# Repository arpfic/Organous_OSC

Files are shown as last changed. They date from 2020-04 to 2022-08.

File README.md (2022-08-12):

# Organous_OSC

This folder contains hardware designs and software for the Orguanous, a prototype pipe organ.

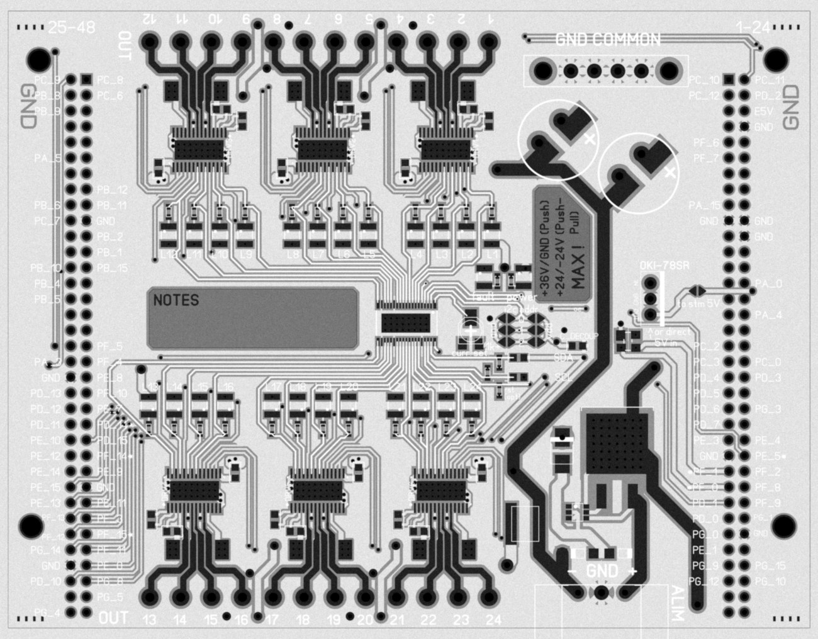
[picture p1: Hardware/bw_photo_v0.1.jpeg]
Organous OSC v0.1


Principal code maintainer : Damien Leblois <damienleb@protonmail.com>

https://arpfic.notion.site/Electronique-pour-orgue-326637f6daa6430288f5e7deb4299960
https://www.violonaroue.fr/Orguanous

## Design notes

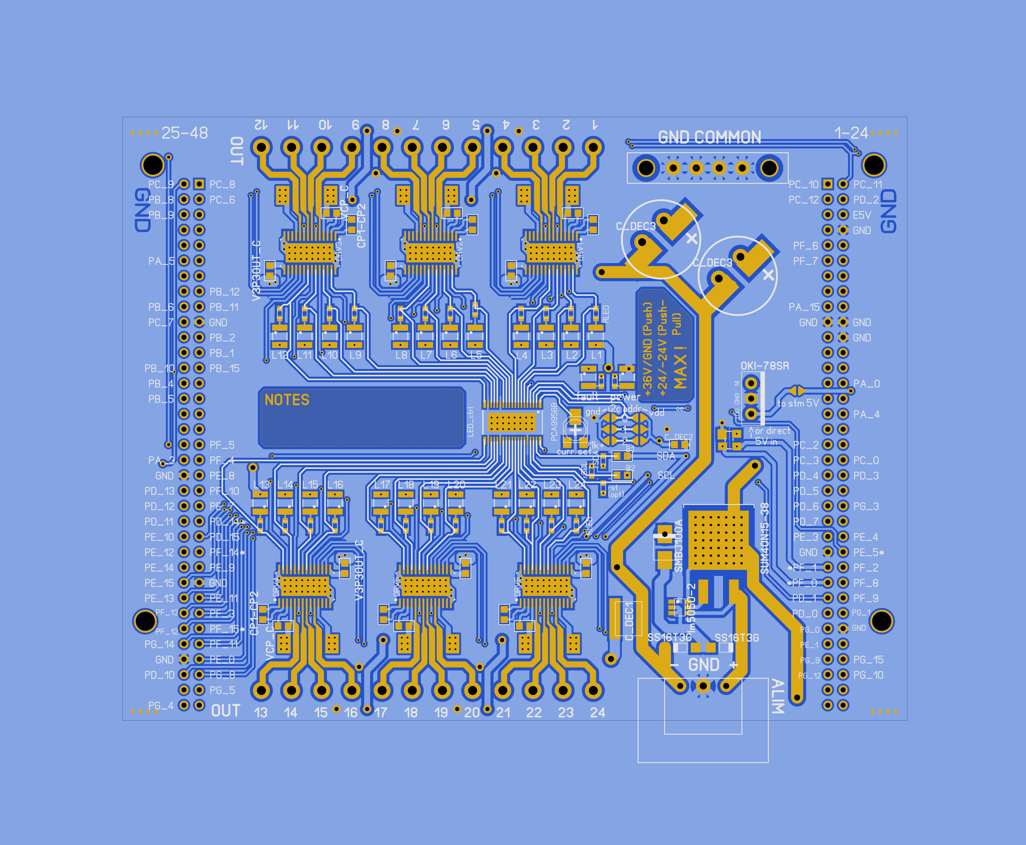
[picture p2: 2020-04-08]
Hardware/Organous_OSC_v0.2_top.png

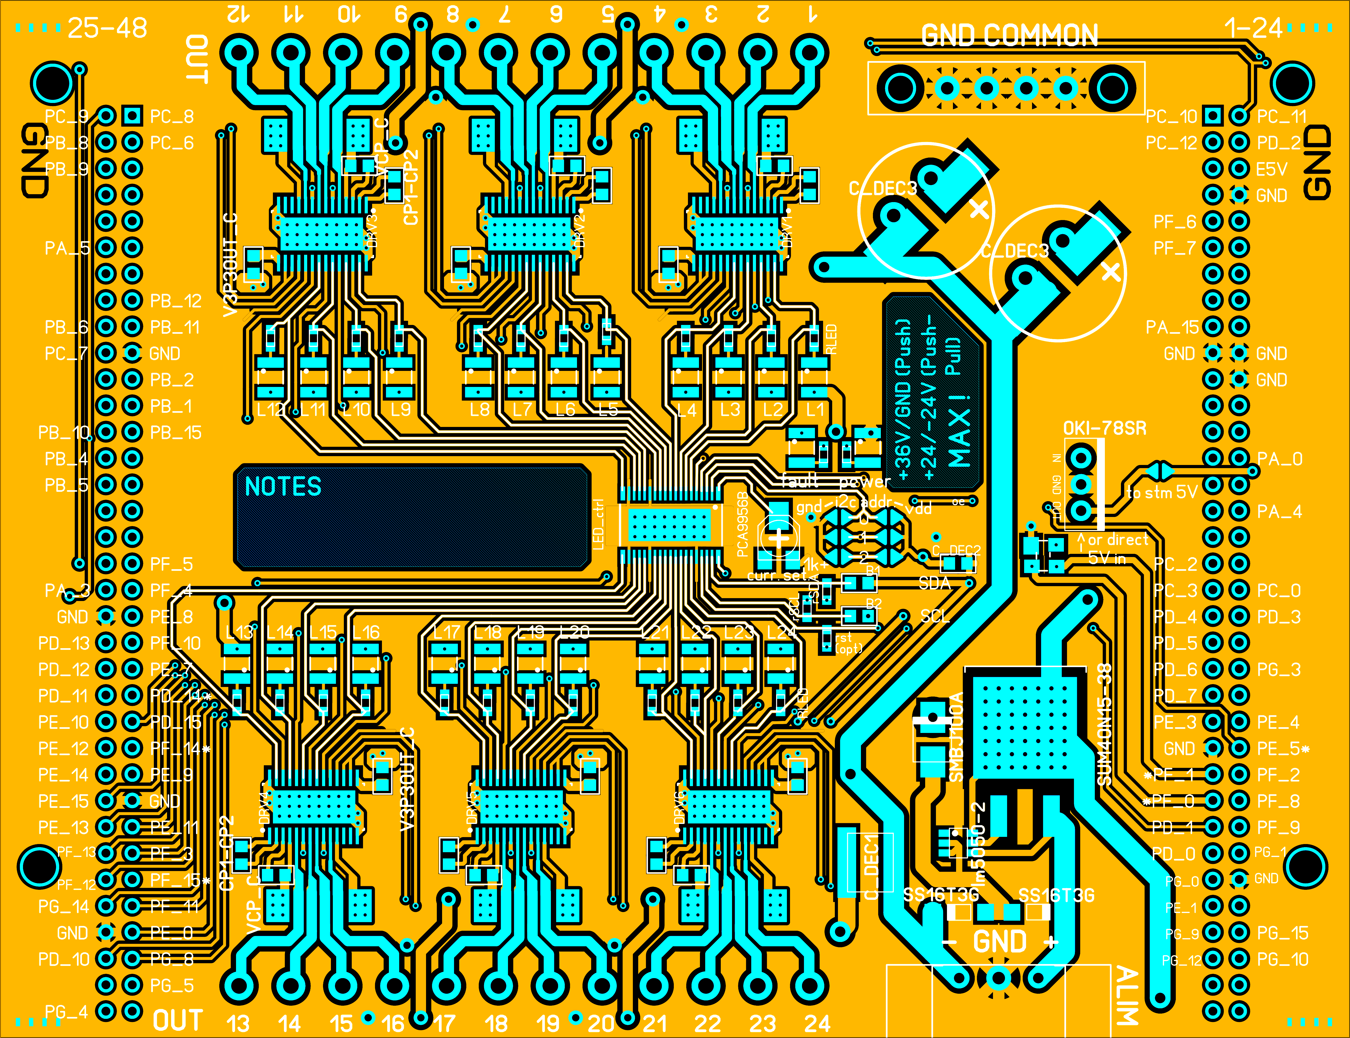
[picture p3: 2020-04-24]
Hardware/carte_osc_fonctions_v0.2_top.png

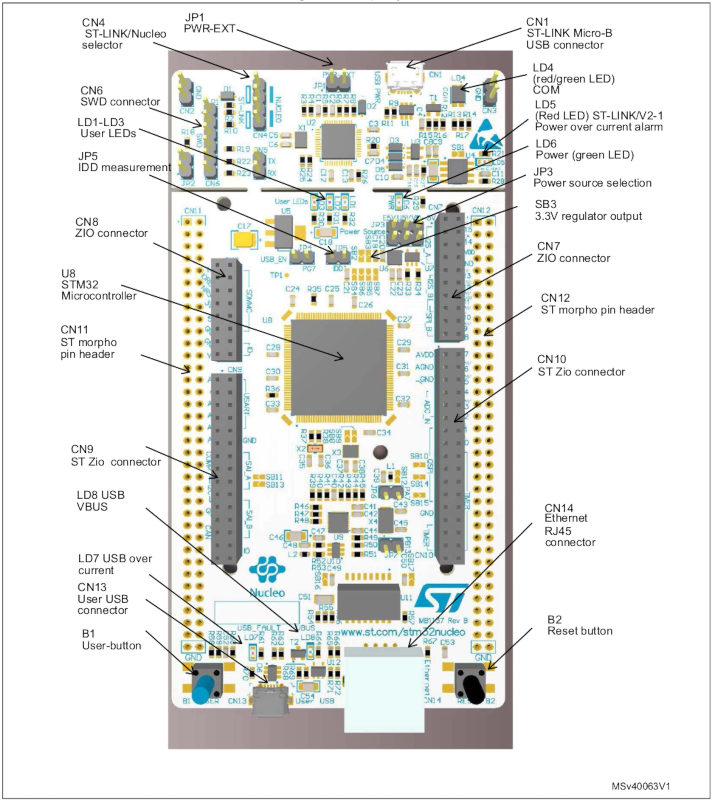
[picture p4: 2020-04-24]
Hardware/Nucleo_144.jpg

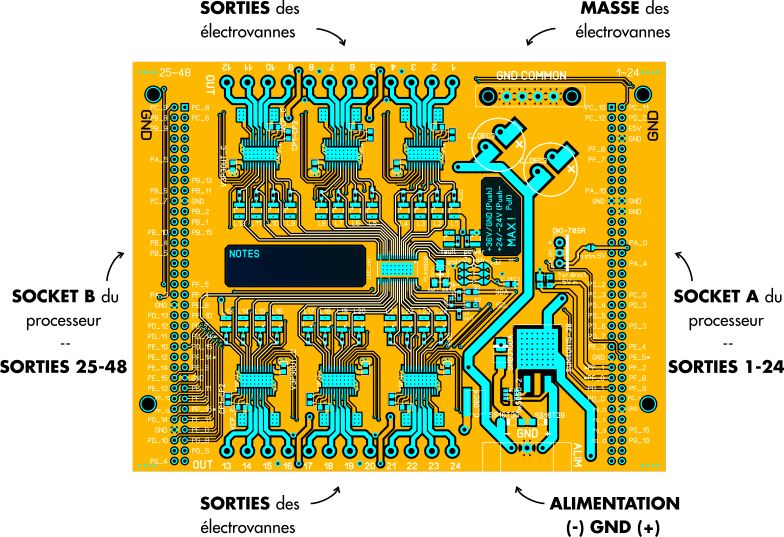
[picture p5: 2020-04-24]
Hardware/carte_osc_fonctions.png

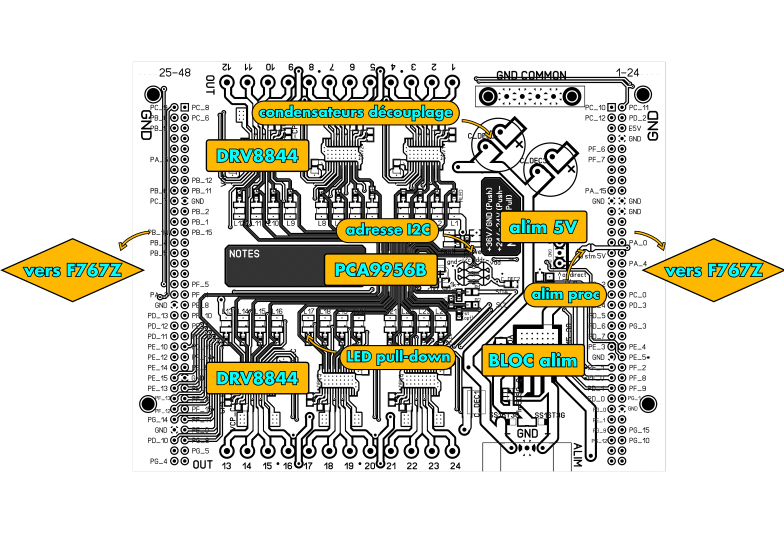
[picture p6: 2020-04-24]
Hardware/carte_osc_fonctions_avancees.png

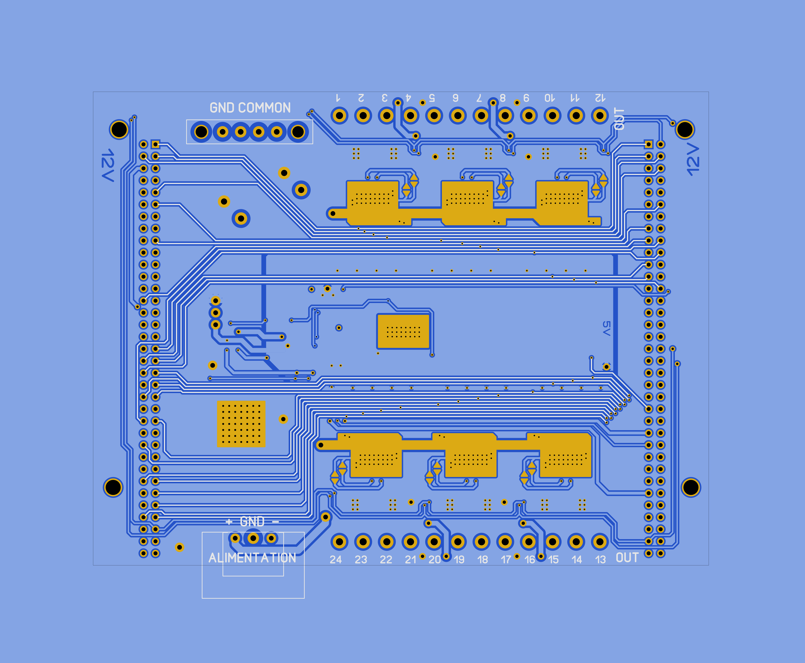
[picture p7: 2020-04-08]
Hardware/Organous_OSC_v0.2_bottom.png

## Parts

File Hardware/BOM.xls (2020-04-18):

ORGANOUS_TOT_10_03_2020
N° Mouser | N° de fab. | Fabricant | N° client | Description | RoHS | Cycle de vie | Qté. | Prix (EUR) | Ext. : (EUR)
855-M20-7832046 | M20-7832046 | Harwin |  | Embases et logements de câbles 20+20 DIL VERTICAL SOCKET TIN | RoHS : conforme |  | 2 | 2,76 € | 5,52 €
595-DRV8844PWPR | DRV8844PWPR | Texas Instruments |  | Contrôleurs et pilotes de moteur / de mouvement / d'allumage Brushed DC motor Solenoid/Relay Drvr | RoHS : conforme |  | 6 | 2,97 € | 17,82 €
580-OKI78SR51.5W36HC | OKI-78SR-5/1.5-W36H-C | Murata |  | Convertisseurs CC-CC non isolés 7.5W 24V 5Vout 1.5A Horizontal Mount | RoHS : conforme |  | 1 | 3,87 € | 3,87 €
771-PCA9956BTWY | PCA9956BTWY | NXP |  | Étage pilote pour LED I2C LED Display Control | RoHS : conforme |  | 1 | 1,41 € | 1,41 €
651-1830619 | 1830619 | Phoenix Contact |  | Borniers enfichable 4 Pos 3.81mm pitch Through Hole Header | RoHS : conforme |  | 1 | 3,27 € | 3,27 €
651-1828362 | 1828362 | Phoenix Contact |  | Borniers enfichable 4 Pos 3.81mm pitch Plug 28-16 AWG Screw | RoHS : conforme |  | 1 | 4,34 € | 4,34 €
490-TBP02R1W-38103BE | TBP02R1W-381-03BE | CUI Devices |  | Borniers enfichable Terminal block, pluggable, w screw lock, 3.81, receptical, 3 pole, blue |  | Nouveau produit | 1 | 0,603 € | 0,60 €
490-TBP02P1W-38103BE | TBP02P1W-381-03BE | CUI Devices |  | Borniers enfichable Terminal block, pluggable, 3.81, plug, 3 pole, slotted screw, blue |  | Nouveau produit | 1 | 0,909 € | 0,91 €
651-1988943 | 1988943 | Phoenix Contact |  | Borniers fixes PTA 1.5/16-5.0 | RoHS : conforme |  | 2 | 2,76 € | 5,52 €
81-BLM18BD471SN1D | BLM18BD471SN1D | Murata |  | Perles de ferrite 0603 470 OHM | RoHS : conforme |  | 2 | 0,09 € | 0,18 €
603-CC603KRX7R9BB103 | CC0603KRX7R9BB103 | Yageo |  | Condensateurs céramique multicouches MLCC - CMS 10nF 50V X7R 10% | RoHS : conforme |  | 6 | 0,09 € | 0,54 €
603-CC603KRX7R9BB104 | CC0603KRX7R9BB104 | Yageo |  | Condensateurs céramique multicouches MLCC - CMS 100nF 50V X7R 10% | RoHS : conforme |  | 7 | 0,09 € | 0,63 €
603-CC0603KR9BB474 | CC0603KRX5R9BB474 | Yageo |  | Condensateurs céramique multicouches MLCC - CMS .47uF 50V 10% 0603 Case Size | RoHS : conforme |  | 6 | 0,531 € | 3,19 €
77-VJ1825Y105MXBAT | VJ1825Y105MXBAT | Vishay |  | Condensateurs céramique multicouches MLCC - CMS 1.0uF 100volts 20% | RoHS : conforme |  | 1 | 1,77 € | 1,77 €
667-EEE-FK2A470AV | EEE-FK2A470AV | Panasonic |  | Condensateurs électrolytiques en aluminium - CMS 100VDC 47uF 20% Anti-Vibe AEC-Q200 | RoHS : conforme | Nouveau produit | 2 | 1,71 € | 3,42 €
863-SS16T3G | SS16T3G | ON Semiconductor |  | Diodes et redresseurs Schottky 1A 60V | RoHS : conforme |  | 2 | 0,144 € | 0,29 €
652-SMBJ100A | SMBJ100A | Bourns |  | Suppresseurs ESD / diodes TVS 100volts 5uA 3.7 Amps Uni-Dir | Conforme à RoHS par dispense |  | 1 | 0,414 € | 0,41 €
926-LM5050MK-2/NOPB | LM5050MK-2/NOPB | Texas Instruments |  | Contrôleurs de tension à remplacement à chaud Hi Side OR-ing FET Cntlr | RoHS : conforme |  | 1 | 1,98 € | 1,98 €
859-LTST-C930KFKT | LTST-C930KFKT | Lite-On |  | DEL standard - CMS Orange Clear 605nm | RoHS : conforme |  | 25 | 0,18 € | 4,50 €
859-LTST-C930GKT | LTST-C930GKT | Lite-On |  | DEL standard - CMS Green Clear 569nm | RoHS : conforme |  | 1 | 0,342 € | 0,34 €
78-SUM80090E-GE3 | SUM80090E-GE3 | Vishay |  | MOSFET 150V Vds 20V Vgs D2PAK (TO-263) | RoHS : conforme |  | 1 | 2,70 € | 2,70 €
771-PRTR5V0U2AX,235 | PRTR5V0U2AX,235 | Nexperia |  | Suppresseurs ESD / diodes TVS Diode TVS Single Uni-Dir 5.5V 4-Pin | RoHS : conforme |  | 1 | 0,468 € | 0,47 €
603-RC0603FR-07270RL | RC0603FR-07270RL | Yageo |  | Résistances à couches épaisses - CMS 270 OHM 1% | Conforme à RoHS par dispense |  | 2 | 0,09 € | 0,18 €
603-RC0603FR-071KL | RC0603FR-071KL | Yageo |  | Résistances à couches épaisses - CMS 1K OHM 1% | Conforme à RoHS par dispense |  | 24 | 0,016 € | 0,38 €
72-TS53YJ-10K | TS53YJ103MR10 | Vishay |  | Résistances ajustables - SMD 5MM SQ SMD 103 | Conforme à RoHS par dispense |  | 1 | 1,13 € | 1,13 €
603-RC0603FR-071K6L | RC0603FR-071K6L | Yageo |  | Résistances à couches épaisses - CMS 1.6K OHM 1% | Conforme à RoHS par dispense |  | 2 | 0,09 € | 0,18 €
859-LTST-C930EKT | LTST-C930EKT | Lite-On |  | DEL standard - CMS Red Clear 621nm | RoHS : conforme |  | 1 | 0,351 € | 0,35 €
144-MTS-11 | MTS-11 | Essentra |  | Écarteurs et entretoises Stndff,Thrd,Hex,Natural,11MM Spc | RoHS : conforme | Nouveau chez Mouser | 2 | 0,72 € | 1,44 €
534-29341 | 29341 | Keystone Electronics |  | Vis et attaches M3 6.0mm NYL SCRW | RoHS : conforme |  | 4 | 0,20 € | 0,40 €
568-NE8FDV-TOP | NE8FDV-TOP | Neutrik |  | Connecteurs modulaires / Connecteurs Ethernet CAT5 D PCB Panel Mnt Rcpt Nickel TOP | RoHS : conforme | Nouveau produit | 1 | 6,78 € | 6,78 €
568-NE8MX-TOP | NE8MX-TOP | Neutrik |  | Connecteurs modulaires / Connecteurs Ethernet CAT5 Cable Carrier Nickel TOP | RoHS : conforme | Nouveau produit | 2 | 3,18 € | 6,36 €
511-NUCLEO-F767ZI | NUCLEO-F767ZI | STMicroelectronics |  | Cartes et kits de développement - ARM 16/32-BITS MICROS | RoHS : conforme |  | 1 | 21,53 € | 21,53 €
855-M20-9981845 | M20-9981845 | Harwin |  | Embases et logements de câbles 18+18 DIL VERTICAL PIN HEADER GOLD HT | RoHS : conforme |  | 2 | 1,13 € | 2,26 €

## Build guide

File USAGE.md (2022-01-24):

## USAGE -- OSC Commands

### MAIN commands

#### MIDI msg : NoteOffType
#### MIDI msg : NoteOnType
#### MIDI msg : ResetAllControllersType
#### MIDI msg : AllNotesOffType

#### OSC msg  : /main/coil ii PORT INTENSITY
 * Purpose   : drive coilOn/coilOff functions
 * Note      : For now, INTENSITY is almost useless : we just launch coilOff if == 0
 * Function  : *menu_main_coil()*

#### OSC msg  : /main/motor iif PORT NEXT_PORT SPEED
 * Purpose  : drive motor function. SPEED set between -1 and +1
 * Note     : This is a PUSH/PULL configuration
 * Function : *menu_main_motor()*

#### OSC msg  : /main/motor_brake ii PORT NEXT_PORT
 * Purpose  : drive motor_brake function (all enable and pwm sets to 1)
 * Note     : This is a PUSH/PULL configuration
 * Function : *menu_main_motor_brake()*

#### OSC msg  : /main/motor_coast ii PORT NEXT_PORT
 * Purpose  : drive motor_coast function (all enable and pwm sets to 0)
 * Note     : This is a PUSH/PULL configuration
 * Function : *menu_main_motor_coast()*

#### OSC msg  : /main/tone f FREQ
 * Purpose   : Play a "note" in class-D style through all DRV8844 OUT and with OE setting
 * Note      : Very experimental and ugly. But promising.
 * Function  : *menu_main_tone()*

### LOWLEVEL commands

#### OSC msg  : /lowlevel/output ii PORT 0/1
 * Purpose   : set/unset OUTPUT with ENABLE pin on DRV8844 (see datasheet)
 * Function  : *menu_lowlevel_output()*

#### OSC msg  : /lowlevel/output_all i 0/1
 * Purpose   : set/unset ALL OUTPUTS with ENABLE pin on DRV8844 (see datasheet)
 * Function  : *menu_lowlevel_output_all()*

#### OSC msg  : /lowlevel/output_state i PORT
 * Purpose   : just return OUTPUT state
 * Function  : *menu_lowlevel_output_state()*

#### OSC msg  : /lowlevel/pwm if PORT RATIO
 * Purpose   : control blinking of LEDS with RATIO[0:1]
 * Function  : *menu_lowlevel_pwm()*

#### OSC msg  : /lowlevel/pwm_all f RATIO
 * Purpose   : control blinking of all LEDS at the same time with RATIO[0:1]
 * Note      : Can be used in conjunction with OE
 * Function  : *menu_lowlevel_pwm_all()*

#### OSC msg  : /lowlevel/pwm_state i PORT
 * Purpose   : read the PWM state of PORT
 * Note      : Nothing for now.
 * Function  : *menu_lowlevel_pwm_state()*

#### OSC msg  : /lowlevel/oe ff CYCLE_RATIO PERIOD_SEC
 * Purpose   : set OE FastPWM config and control blinking of all LEDS at the same time
 * Note      : can be used in conjunction with other functions -- currently we DON'T touch ENABLE table
 * Function  : *menu_lowlevel_oe()*

### Tools commands

#### OSC msg  : /tools/connect NONE (Bang)
 * Purpose   : connect NUCLEO_F767ZI to client (set IP address)
 * Function  : *menu_tools_connect()*

#### OSC msg  : /tools/debug NONE (Bang)
 * Purpose   : set debug ON to send many messages to client
 * Function  : *menu_tools_debug()*

#### OSC msg  : /tools/hardreset NONE (Bang)
 * Purpose   : Hard reset the board
 * Function  : *menu_tools_hardreset()*

#### OSC msg  : /tools/softreset NONE (Bang)
 * Purpose   : "Soft reset" the board : set to init as possible
 * Function  : *menu_tools_softreset()*

#### OSC msg  : /tools/forceoff_all NONE (Bang)
 * Purpose   : re-init OE and call forceoff ALLPORTS
 * Function  : *menu_tools_forceoff_all()*

#### OSC msg  : /tools/count i COUNT
 * Purpose   : Just ping pong from client for network reliability test
 * Function  : *menu_tools_count()*

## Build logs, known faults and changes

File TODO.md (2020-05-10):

## TODO

###### Software

* faire un registre précis de l'état des configs, que puredata peut rappeler
* créer un pwm software pour les ENABLE
* -ok- régler le problème des deux réseaux et de l'initialisation des IP sur puredata
* -not so ok- Distinguer l'usage d'un seul ou des deux drivers à la fois
* -ok- Tester le reliability d'UDP, et tenter d'implémenter un ack avec puredata
* -ok- Commenter le code
* Tester l'inversion 0->1 du pca99x6B au repos
* Retourner un code d'erreur si aucun pca995xB n'est trouvé
* Écrire une doc pour la carte elle-même
* Gérer les erreurs au niveau du pca995xB lui-même
* -ok- Écrire un vrai README
* Discriminer les messages de debug
* Chercher à créer un fichier de config directement dans le système de fichier du NUCLEO ?
* -ok- Licencier le code correctement (À présent il y a du Apache/MIT)
* Créer un wrapper midi (et une interface qui émanciperait de puredata)

###### Hardware

* -ok- Envisager sérieusement une carte d'extension qui relèverait le courant.
* -ok- Prévoir des entretoises et un support de fixation contre les sommiers
* Envisager une boîte de protection ?

## BUGS :

* Bug entre coil et motor quand on utilise les deux en même temps ?
* -ok- Fonction tone cassée depuis la MAJ
* Encore quelques derniers problèmes d'IP : /debug ss "SURAIGU mod. (v0.1):" "255.255.255.255"
* -ok- OVERCURRENT fonction un peu bavarde ! Il faut tester avec un bon bouncing

## MBED INSTALLATION

* Télécharger : https://developer.arm.com/tools-and-software/open-source-software/developer-tools/gnu-toolchain/gnu-rm/downloads

```
sudo apt install python2.7 python-pip git mercurial
pip install mbed-cli
mbed import https://github.com/arpfic/Organous_OSC.git
cd Organous_OSC/mbed-os
pip install -U -r requirements.txt
cd ..
mbed config -G GCC_ARM_PATH ~/Travaux/gcc-arm-none-eabi-9-2019-q4-major/bin
mbed target NUCLEO_F767ZI
mbed compile
``````

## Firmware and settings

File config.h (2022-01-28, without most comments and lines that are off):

#define OSC_BOARD                                   1
#define SOFT_VER                                    "v0.3"
#if OSC_BOARD == 1
    #define IF_NAME                                 "SURAIGU board"
    #define IF_OSC_NAME                             "suraig"
    #define B_SIDE                                  1
    #define A_SIDE_OUTS                             24
    #define B_SIDE_OUTS                             18
    #define IF_BASENOTE                             79
    #define A_SIDE_I2C_TAG                         0xD2 // Vdd-GND-Vdd
    #define B_SIDE_I2C_TAG                         0xD2 // GND-Vdd-GND
    #define DEFAULT_I2C_TAG                        0xD2 // GND-Vdd-GND
    #define ENABLE_PINS                             24
    #define MAX_OUT_ENABLED                         OUT_ENABLED4
    #define OUT_MAXUSERS                            1
    #define OFF                                     255
    #define ON                                      0
    #define COIL_ATTACK_DELAY                       20
    #define COIL_ATTACK                             255
    #define COIL_SUSTAIN                            (uint8_t)230
    #define DRV_EN1                                 PC_10
    #define DRV_EN2                                 PC_12
    #define DRV_EN3                                 PD_2
    #define DRV_EN4                                 PF_6
    #define DRV_EN5                                 PF_7
    #define DRV_EN6                                 PA_15
    #define DRV_EN7                                 PA_0
    #define DRV_EN8                                 PE_4
    #define DRV_EN9                                 PC_2
    #define DRV_EN10                                PC_0
    #define DRV_EN11                                PC_3
    #define DRV_EN12                                PD_3
    #define DRV_EN13                                PD_4
    #define DRV_EN14                                PG_3
    #define DRV_EN15                                PD_5
    #define DRV_EN16                                PD_6
    #define DRV_EN17                                PE_3
    #define DRV_EN18                                PF_2
    #define DRV_EN19                                PG_1
    #define DRV_EN20                                PD_0
    #define DRV_EN21                                PG_0
    #define DRV_EN22                                PE_1
    #define DRV_EN23                                PG_15
    #define DRV_EN24                                PG_9
    #define PCA_A_SCL                               PF_1
    #define PCA_A_SDA                               PF_0
    #define PCA_A_OE                                PE_5
    #define PCA_A_RST                               PD_1
    #define DRV_A_RST                               PG_12
    #define DRV_A_FAULT                             PC_11
    #define DRV_EN25                                PC_8
    #define DRV_EN26                                PC_6
    #define DRV_EN27                                PB_8
    #define DRV_EN28                                PB_9
    #define DRV_EN29                                PA_5
    #define DRV_EN30                                PB_12
    #define DRV_EN31                                PB_11
    #define DRV_EN32                                PB_6
    #define DRV_EN33                                PC_7
    #define DRV_EN34                                PB_2
    #define DRV_EN35                                PB_1
    #define DRV_EN36                                PB_10
    #define DRV_EN37                                PD_15
    #define DRV_EN38                                PE_15
    #define DRV_EN39                                PE_13
    #define DRV_EN40                                PE_11
    #define DRV_EN41                                PF_13
    #define DRV_EN42                                PF_3
    #define DRV_EN43                                PF_12
    #define DRV_EN44                                PG_14
    #define DRV_EN45                                PF_11
    #define DRV_EN46                                PE_0
    #define DRV_EN47                                PD_10
    #define DRV_EN48                                PG_8
    #define PCA_B_SCL                               PF_14
    #define PCA_B_SDA                               PF_15
    #define PCA_B_OE                                PD_14
    #define PCA_B_RST                               PE_9
    #define DRV_B_RST                               PG_5
    #define DRV_B_FAULT                             PC_9
    #define MIDI_CHANNEL_A                          16
    #define MIDI_CHANNEL_B                          8
    #define MIDI_CHANNEL_A_SIZE                     11
    #define MIDI_CHANNEL_B_OFFSET                   0
#elif OSC_BOARD == 2
    #define IF_NAME                                 "RESPIRATOR board"
    #define IF_OSC_NAME                             "respi"
    #define B_SIDE                                  0
    #define A_SIDE_OUTS                             24
    #define IF_BASENOTE                             67
    #define A_SIDE_I2C_TAG                         0xD2 // Vdd-GND-Vdd
    #define DEFAULT_I2C_TAG                        0xD2 // GND-Vdd-GND
    #define ENABLE_PINS                             24
    #define MAX_OUT_ENABLED                         OUT_ENABLED4
    #define OUT_MAXUSERS                            4
    #define OFF                                     255
    #define ON                                      0
    #define COIL_ATTACK_DELAY                       20
    #define COIL_ATTACK                             255
    #define COIL_SUSTAIN                            (uint8_t)230
    #define DRV_EN1                                 PC_8
    #define DRV_EN2                                 PC_6
    #define DRV_EN3                                 PB_8
    #define DRV_EN4                                 PB_9
    #define DRV_EN5                                 PA_5
    #define DRV_EN6                                 PB_12
    #define DRV_EN7                                 PB_11
    #define DRV_EN8                                 PB_6
    #define DRV_EN9                                 PC_7
    #define DRV_EN10                                PB_2
    #define DRV_EN11                                PB_1
    #define DRV_EN12                                PB_10
    #define DRV_EN13                                PD_15
    #define DRV_EN14                                PE_15
    #define DRV_EN15                                PE_13
    #define DRV_EN16                                PE_11
    #define DRV_EN17                                PF_13
    #define DRV_EN18                                PF_3
    #define DRV_EN19                                PF_12
    #define DRV_EN20                                PG_14
    #define DRV_EN21                                PF_11
    #define DRV_EN22                                PE_0
    #define DRV_EN23                                PD_10
    #define DRV_EN24                                PG_8
    #define PCA_A_SCL                               PF_14
    #define PCA_A_SDA                               PF_15
    #define PCA_A_OE                                PD_14
    #define PCA_A_RST                               PE_9
    #define DRV_A_RST                               PG_5
    #define DRV_A_FAULT                             PC_9
    #define MIDI_CHANNEL_A                          1
    #define MIDI_CHANNEL_B                          NULL
    #define MIDI_CHANNEL_A_SIZE                     24
    #define MIDI_CHANNEL_B_OFFSET                   0
#endif
#define MIDI_UART_TX                            PB_4
#define MIDI_UART_RX                            PE_7
#define MIDIMAIL_SIZE                           64
#define MIDI_MAX_MSG_LENGTH                     4 // Max message size. SysEx can be up to 65536.
#define LED_GREEN                               LED1
#define LED_BLUE                                LED2
#define LED_RED                                 LED3
#define OSC_CLIENT_PORT                         9000
#define MAX_PQT_LENGTH                          4096
#define MAX_PQT_SENDLENGTH                      512
#define PACKETS_TABLE_SIZE                      32
#define QUEUE_MSG_EVENTS                        32
#define QUEUE_IO_EVENTS                         1024

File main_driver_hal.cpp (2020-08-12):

/*
    Copyright (c) 2020 Damien Leblois
    Permission is hereby granted, free of charge, to any person obtaining a copy
    of this software and associated documentation files (the "Software"), to deal
    in the Software without restriction, including without limitation the rights
    to use, copy, modify, merge, publish, distribute, sublicense, and/or sell
    copies of the Software, and to permit persons to whom the Software is
    furnished to do so, subject to the following conditions:
    The above copyright notice and this permission notice shall be included in
    all copies or substantial portions of the Software.
    THE SOFTWARE IS PROVIDED "AS IS", WITHOUT WARRANTY OF ANY KIND, EXPRESS OR
    IMPLIED, INCLUDING BUT NOT LIMITED TO THE WARRANTIES OF MERCHANTABILITY,
    FITNESS FOR A PARTICULAR PURPOSE AND NONINFRINGEMENT. IN NO EVENT SHALL THE
    AUTHORS OR COPYRIGHT HOLDERS BE LIABLE FOR ANY CLAIM, DAMAGES OR OTHER
    LIABILITY, WHETHER IN AN ACTION OF CONTRACT, TORT OR OTHERWISE, ARISING FROM,
    OUT OF OR IN CONNECTION WITH THE SOFTWARE OR THE USE OR OTHER DEALINGS IN
    THE SOFTWARE.
*/
#include "main_driver_hal.h"

// Default constructor
CoilDriver::CoilDriver(PinName _i2c_sda, PinName _i2c_scl, PinName _pinoe,
                       PinName _pindrv_rst, PinName _pindrv_fault, DigitalOut *_driver_table,
                       event_callback_t _i2c_cb_function, char _i2c_addr)
    :   i2c_p( new I2C( _i2c_sda, _i2c_scl ) ), i2c( *i2c_p ),
        i2c_cb_function(_i2c_cb_function),
        i2c_addr(_i2c_addr),
        led_drv_p(new PCA9956A(i2c, i2c_cb_function, i2c_addr)), led_drv(*led_drv_p),
        oe(_pinoe),
        drv_rst(_pindrv_rst),
        drv_fault(_pindrv_fault),
        drv_ena(_driver_table)
{
    init();
}

CoilDriver::~CoilDriver()
{
    if ( NULL != led_drv_p )
        delete  led_drv_p;
    if ( NULL != i2c_p )
        delete  i2c_p;
}

/* init()
 * - drv_rst sets to 0 to enable drivers (see the DRV8844 datasheet)
 * - I2C freq to Fastmode (1Mhz)
 * - LED current sets to 0.5 to activate DRV8844
 * - Remember that OUTPUTS are inversed because of the PCA9956A mechanism, so
 *   we have to set all LEDS to ON.
 * - OUTRegister stack is initiazed to OUT_IDLE
 * - OE (PCA9956A) have to be 0 to activate OUTPUTS.
 * - TODO: maybe set drv_rst = 1 ?
 * - coilOn queue and callback is started
 */
void CoilDriver::init( void )
{
    drv_rst = 0;
    i2c.frequency(1000000);
    led_drv.current(ALLPORTS, 127); //  Set all ports output current 50%
    led_drv.pwm(ALLPORTS, OFF);     //  Set all ports output to OFF
    // oe = 0 means always on
    oe.write(0.0f);
    oe.period(1.0f);
    drv_rst = 1;
    // coil* Attack-sustain Thread callback start
    coilThrd.start(callback(&coilQueue, &EventQueue::dispatch_forever));
}

/*----------------------------------------------------------------------------/
/  LOW-LEVEL FUNCTIONS                                                        /
/----------------------------------------------------------------------------*/
/* Simple on() function, whose purpose is to set :
 * - PWM with PCA9956A, and
 * - ENABLE with NUCLEO_F767ZI's GPIO to DRV8844
 */
void CoilDriver::on(int port, uint8_t ratio)
{
    // NB: ALLPORTS is already implemented into Class
    if (port == ALLPORTS) {
        for (int i = 0; i < ENABLE_PINS; i++) {
            if (outRegister.reg_pushPort(i, ratio, true) != -1) {
                led_drv.pwm(i, 255 - ratio);
                drv_ena[i] = 1;
            }
        }
    } else {
        if (outRegister.reg_pushPort(port, ratio, true) != -1) {
        led_drv.pwm(port, 255 - ratio);
        // Enable the OUT
        drv_ena[port] = 1;
        }
    }
}

/* Same idea with off()
 */
void CoilDriver::off(int port)
{
    char user = 0;
    int value = 0; 
    bool enable = false;

    if (port == ALLPORTS) {
        for (int i = 0; i < ENABLE_PINS; i++) {
            if (outRegister.reg_pullPort(i, &user, &value, &enable) != -1) {
                drv_ena[i] = enable;
                led_drv.pwm(i, (255 - value));
            }
        }
    } else {
        if (outRegister.reg_pullPort(port, &user, &value, &enable) != -1) {
            drv_ena[port] = enable;
            led_drv.pwm(port, (255 - value));
        }
    }
}

/* Same as off(), but the stack is flushed
 */
void CoilDriver::forceoff(int port)
{
    if (port == ALLPORTS) {
        for (int i = 0; i < ENABLE_PINS; i++) {
            outRegister.resetAll();
            drv_ena[i] = 0;
            led_drv.pwm(i, OFF);
        }
    } else {
        outRegister.resetPort(port);
        drv_ena[port] = 0;
        led_drv.pwm(port, OFF);
    }
}

/* Simple glue function to set PWM in PCA9956A.
 */
void CoilDriver::pwmSet(int port, uint8_t ratio)
{
    if (port == ALLPORTS) {
        for (int i = 0; i < ENABLE_PINS; i++) {
            if (outRegister.reg_readUser(i) == 0)
                outRegister.reg_increaseUser(i);
            outRegister.reg_writeValue(i, ratio);
        }
        led_drv.pwm(ALLPORTS, 255 - ratio);
    } else {
        if (outRegister.reg_readUser(port) == 0)
            outRegister.reg_increaseUser(port);
        outRegister.reg_writeValue(port, ratio);
        led_drv.pwm(port, 255 - ratio);
    }
}

/* Simple function to enable/disable ENABLE_PINS (DRV8844)
 */
void CoilDriver::drvEnable(int port, int state)
{
    if (state >= 0 && state <= 1) {
        if (port == ALLPORTS) {
            for (int i = 0; i < ENABLE_PINS; i++) {
                if (outRegister.reg_readUser(i) == 0)
                    outRegister.reg_increaseUser(i);
                outRegister.reg_writeEnable(i, (bool)state);
                drv_ena[i] = state;
            }
        } else {
            if (outRegister.reg_readUser(port) == 0)
                outRegister.reg_increaseUser(port);
            outRegister.reg_writeEnable(port, (bool)state);
            drv_ena[port] = state;
        }
    }
}

/*----------------------------------------------------------------------------/
/  HIGH-LEVEL FUNCTIONS                                                      /
/----------------------------------------------------------------------------*/
/* Internal callback function called by coilQueue in coilOn() :
 * Coil sustain to COIL_SUSTAIN PWM.
 */
void CoilDriver::coilSustain(int port, uint8_t sustain, int sustain_user)
{
    // Is the state changed between call_in() ?
    if (sustain_user == outRegister.reg_readUser(port)) {
        outRegister.reg_cleanValues(port);
        outRegister.reg_decreaseUser(port);
        if (outRegister.reg_pushPort(port, sustain, true) != -1) {
            // ena still 1
            led_drv.pwm(port, 255 - sustain);
        }
    }
}

/* Set the coil to attack PWM ratio, and...
 * execute coilSustain() after a delay with a queue to PWM ratio sustain.
 * TODO: don't call the queue if error
 */
void CoilDriver::coilOn(int port, uint8_t attack, uint8_t sustain, int millisec)
{
    on(port, attack);
    int sustain_user = outRegister.reg_readUser(port);
    coilQueue.call_in(millisec, this, &CoilDriver::coilSustain, port, sustain, sustain_user);
}

// Same but with fixed COIL_ATTACK_DELAY millisec.
void CoilDriver::coilOn(int port)
{
    on(port, COIL_ATTACK);
    int sustain_user = outRegister.reg_readUser(port);
    coilQueue.call_in(COIL_ATTACK_DELAY, this, &CoilDriver::coilSustain, port, COIL_SUSTAIN, sustain_user);
}

// gluecode to off()
void CoilDriver::coilOff(int port)
{
    off(port);
}

// Write PWM ratio (0-255) to FastPWM oe
void CoilDriver::oeCycle(float ratio)
{
    float r = outRegister.reg_writeOEratio(ratio);
    if (r != -1)
        oe.write(r);
}

// Same but with the period
void CoilDriver::oePeriod(float period_sec)
{
    float r = outRegister.reg_writeOEperiod(period_sec);
    if (r != -1)
        oe.period(r);
}

/* Set ENABLE and the motor's PWM connected to IN1-IN2 or IN3-IN4 of a DRV8844
 * in a PUSH-PULL style
 */
int CoilDriver::motor(int port, int next_port, int speed){
    if (next_port % 2 && next_port == port + 1 &&
            speed >= -255 && speed <= 255) {
        if (speed < 0) {
            // Set PWM to PUSH PULL
            led_drv.pwm(port,      (uint8_t)(255 + speed));// Note the "+"
            led_drv.pwm(next_port, OFF);// inversed :)
        } else if (speed > 0) {
            led_drv.pwm(next_port, (uint8_t)(255 - speed));
            led_drv.pwm(port,      OFF);
        } else { // speed == 0
            led_drv.pwm(port,      OFF);
            led_drv.pwm(next_port, OFF);
        }
        // Open valves !
        drv_ena[port]      = 1;
        drv_ena[next_port] = 1;
        return  0;
    } else {
        return -1;
    }
}

// Brake the motor by turning BOTH ENABLE to 1 *and* the PWM to NULL (1.0)
int CoilDriver::motorBrake(int port, int next_port) {
    if (next_port % 2 && next_port == port + 1) {
        // Set PWM to MAXIMUM
        led_drv.pwm(port,      OFF);
        led_drv.pwm(next_port, OFF);
        // Set ENABLE to 1
        drv_ena[port]      = 1;
        drv_ena[next_port] = 1;
        return  0;
    } else {
        return -1;
    }
}

// Coast the motor by turning BOTH ENABLE to 0 *and* the PWM to NULL (1.0)
int CoilDriver::motorCoast(int port, int next_port){
    if (next_port % 2 && next_port == port + 1) {
        // Set PWM to MINIMUM
        led_drv.pwm(port,      OFF);
        led_drv.pwm(next_port, OFF);
        // Set ENABLE to 1
        drv_ena[port]      = 0;
        drv_ena[next_port] = 0;
        return  0;
    } else {
        return -1;
    }
}

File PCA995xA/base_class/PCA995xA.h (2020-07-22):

/** PCA995xA constant current LED driver family
 *
 *  Abstract class for PCA995xA family
 *  No instance can be made from this class
 *
 *  @class   PCA9956A
 *  @author  Akifumi (Tedd) OKANO, NXP Semiconductors
 *  @version 0.5
 *  @date    25-Feb-2015
 *
 *  Released under the Apache 2 license
 */

#ifndef     MBED_PCA995xA
#define     MBED_PCA995xA

#include    "mbed.h"
#include    "CompLedDvrCC.h"

#define     ALLPORTS        0xFF
#define     DEFAULT_PWM     1.0
#define     DEFAULT_CURRENT 0.1

/** Abstract class for PCA995xA family
 *  
 *  No instance can be made from this class
 */
class PCA995xA
{
public:
    PCA995xA( PinName i2c_sda, PinName i2c_scl, event_callback_t cb_function, char i2c_address = DEFAULT_I2C_ADDR );
    PCA995xA( I2C &i2c_obj, event_callback_t cb_function, char i2c_address = DEFAULT_I2C_ADDR );
    virtual ~PCA995xA();

    void            reset( void );

    virtual void    pwm( int port, char v );
    virtual void    current( int port, char vp );

    void            pwm( char *vp );
    void            current( char *vP );
    
    virtual int     number_of_ports( void )             = 0;

    void            write( char reg_addr, char data );
    void            write( char *data, int length );
//    char            read( char reg_addr );
//    void            read( char reg_addr, char *data, int length );

protected:
    enum {
        DEFAULT_I2C_ADDR    = 0xC0,
        AUTO_INCREMENT      = 0x80
    };
    
    void            internal_cb_handler(int event);
    char rx_buf[1];

private:
    virtual char    pwm_register_access( int port )     = 0;
    virtual char    current_register_access( int port ) = 0;

    I2C             *i2c_p;
    I2C             &i2c;
    event_callback_t cb_function_p;
    char            address;    //  I2C slave address
}
;

#endif  //  MBED_PCA995xA

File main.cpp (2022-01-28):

/*
    Copyright (c) 2020 Damien Leblois
    Permission is hereby granted, free of charge, to any person obtaining a copy
    of this software and associated documentation files (the "Software"), to deal
    in the Software without restriction, including without limitation the rights
    to use, copy, modify, merge, publish, distribute, sublicense, and/or sell
    copies of the Software, and to permit persons to whom the Software is
    furnished to do so, subject to the following conditions:
    The above copyright notice and this permission notice shall be included in
    all copies or substantial portions of the Software.
    THE SOFTWARE IS PROVIDED "AS IS", WITHOUT WARRANTY OF ANY KIND, EXPRESS OR
    IMPLIED, INCLUDING BUT NOT LIMITED TO THE WARRANTIES OF MERCHANTABILITY,
    FITNESS FOR A PARTICULAR PURPOSE AND NONINFRINGEMENT. IN NO EVENT SHALL THE
    AUTHORS OR COPYRIGHT HOLDERS BE LIABLE FOR ANY CLAIM, DAMAGES OR OTHER
    LIABILITY, WHETHER IN AN ACTION OF CONTRACT, TORT OR OTHERWISE, ARISING FROM,
    OUT OF OR IN CONNECTION WITH THE SOFTWARE OR THE USE OR OTHER DEALINGS IN
    THE SOFTWARE.
*/
#include "main.h"
#include "MIDIMessage.h"
#include "ThisThread.h"
#include "main_debug.h"
#include "menu.h"
#include <cstdlib>

// Handlers
static void handle_udp_socket()
{
    queue_io.call(receive_udp_message);
}

static void handle_tcp_socket()
{
    return;
}

// Read data from the socket
static void receive_udp_message()
{
    // Zeroing the buffer. Bof
    // memset(mainpacket_buffer, 0, sizeof(mainpacket_buffer));
    // Read all messages
    bool something_in_socket = true;
    while (something_in_socket) {
        // Copy to the temporary buffer
        mainpacket_length = udp_socket->recvfrom(client_addr, mainpacket_buffer, sizeof(mainpacket_buffer) - 1);
        if (mainpacket_length > 0) {
            // Allocate a new packet in the buffer table :
            socketpacket* new_packet = create_buffer(mainpacket_length);
            if (new_packet == NULL) {
                led_red = !led_red;
                delete_array(new_packet);
            } else {
		// Copy to the packet...
                memcpy(new_packet->data, mainpacket_buffer, mainpacket_length);
                new_packet->size = mainpacket_length;
                // ... then inject it to Circularbuffer
                socketpacket_buf.push(new_packet);
                // The Thread needs to wake up !
                oscTask.flags_set(0x1);
            }
        } else if (mainpacket_length != NSAPI_ERROR_WOULD_BLOCK) {
            // Error while receiving
            led_red = !led_red;
            something_in_socket = false;
        } else {
            // Or there was nothing to read.
            something_in_socket = false;
        }
    }
}

// Read data from the socket
static void receive_tcp_message()
{
    return ;
}

/* Init NUCLEO_F767ZI message. See main.h
 */
void init_msgON()
{
    char buffer[MAX_PQT_SENDLENGTH];

    sprintf(buffer, "UP ! My IP address is :");
    sprintf(buffer + strlen(buffer), " %s", const_cast<char*>(ip->get_ip_address()));
    sprintf(buffer + strlen(buffer), " Please connect");

    debug_OSC(buffer);

    // Everything is OK
    led_green = !led_green;
}

/* Send UDP packet through UDPSocket. Call by debug*()
 */
static void send_UDPmsg(char* incoming_msg, int in_length)
{
    client_addr->set_ip_address(master_address);
    client_addr->set_port(OSC_CLIENT_PORT);
    udp_socket->sendto(*(client_addr), incoming_msg, in_length);
}

/* Button basic functions : we just resend init_msgON() when pressed
 */
void button_pressed()
{
    led_red = 1;
    if (eth->get_connection_status() == NSAPI_STATUS_GLOBAL_UP)
        queue_msg.call(init_msgON);
}

void button_released()
{
    led_red = 0;
}

// TONE experimental BROKEN function -- Interrupt routine
// used to output next analog sample whenever a timer interrupt occurs
void sampler_timer()
{
    // send next analog sample out to D to A
    driver_A->oeCycle(sinusoid_data[k]);
#if B_SIDE == 1
    driver_B->oeCycle(sinusoid_data[k]);
#endif
    // increment pointer and wrap around back to 0 at 128
    k = (k+2) & 0x07F;
}

/* (Very) basic implementation of EthernetInterface Status callback : it just
 * reset the board when disconnected. TODO: let's DO it better.
 */
void eth_status_callback(nsapi_event_t status, intptr_t param)
{
    if (param != NSAPI_STATUS_GLOBAL_UP && param != NSAPI_STATUS_LOCAL_UP)
        NVIC_SystemReset(); // Just reset the main board and voilà !
}

/* Callbacks to DRV8844 error PINS PinDetect : means OVERCURRENT or OVERTEMP, etc.
 * ---> We send an OSC Message
 */
void driver_A_error_handler()
{
    if (debug_on) debug_OSC("ERROR (temp/voltage/current) on card A. Please reset");
    led_red = 1;
}

void driver_B_error_handler()
{
    if (debug_on) debug_OSC("ERROR (temp/voltage/current) on card B. Please reset");
    led_red = 1;
}

void osc_task(){
    /* Here we realy decode OSC messages -- and we parse addr to menu subfunctions
    */
    while (1) {
        ThisThread::flags_wait_any(0x1);
        while (!socketpacket_buf.empty()) {
            // Test if we are full
            if (socketpacket_buf.full() && debug_on)
                debug_OSC("Circularbuffer full : please slow down the flow !");

            socketpacket* packet;
            socketpacket_buf.pop(packet);

            if (debug_on) debug_OSCmsg(packet->data, packet->size);

            tosc_message osc;
            p_osc = &osc;

            if (tosc_isBundle(packet->data)) {
                // Blink for fun
                led_blue = !led_blue;

                tosc_bundle bundle;
                tosc_parseBundle(&bundle, packet->data, packet->size);

                while (tosc_getNextMessage(&bundle, &osc)) {
                    for (menu_cases* p_case = cases;
                            p_case != cases + sizeof(cases) / sizeof(cases[0]);
                            p_case++) {
                        if (strncmp(tosc_getAddress(&osc), p_case->menu_string,
                                    strlen(p_case->menu_string)) == 0) {
                            (*p_case->menu_func)();
                        }
                    }
                }
            } else if (!tosc_parseMessage(&osc, packet->data, packet->size)) {
                // Blink for fun
                led_blue = !led_blue;

                for (menu_cases* p_case = cases;
                        p_case != cases + sizeof(cases) / sizeof(cases[0]);
                        p_case++) {
                            if (strncmp(tosc_getAddress(&osc), p_case->menu_string,
                                    strlen(p_case->menu_string)) == 0) {
                            (*p_case->menu_func)();
                        }
                }
            } else {
                led_red = !led_red;
            }
    // Delete memory allocation
        delete_array(packet);
        }
    }
}
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

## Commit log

2020-04-05 tOSC migration finished + mbed update + no more known bugs (dhcp etc)
    [config.h, main.cpp, main_driver_hal.cpp]
2020-04-06 basic driver registrer + driver errors handler
    [config.h, main.cpp, main_driver_hal.cpp]
2020-04-08 More files
    [BOM.xls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]
2020-04-18 I2C address config
    [BOM.xls]
2020-04-25 udp bug resolved ?
    [main.cpp, menu.h]
2020-04-28 menu lowlevel functions && layout update
    [Organous_OSC_v0.2.DRL, Organous_OSC_v0.2_copper_bottom.gbr, Organous_OSC_v0.2_copper_top.gbr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]
2020-04-29 added motor* commands
2020-06-23 Add a circular buffer between UDP ad I2C
2020-06-24 added socket
2020-07-22 support of multiple boards
2022-01-24 Configurable UART PINs + Msg on full mailbox
2022-01-25 handle the impossible case when Midi buffer is full
2022-01-28 rewrite midi interrupt + full debug
